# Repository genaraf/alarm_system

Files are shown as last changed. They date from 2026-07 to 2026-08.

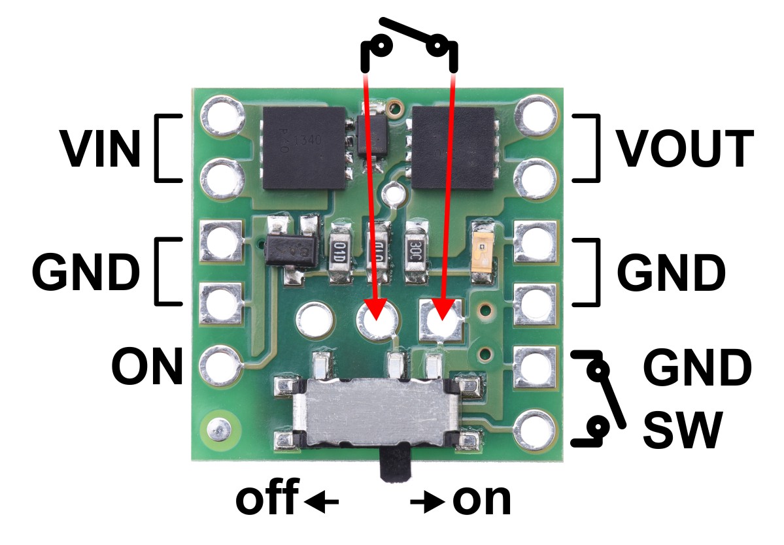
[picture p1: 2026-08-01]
doc/mosfet switch.jpg

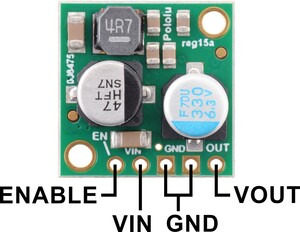
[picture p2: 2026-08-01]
doc/dc-dc.jpg

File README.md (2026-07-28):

# Alarm System on Blynk IoT + ESP32-C3

Проект реализует сирену на `ESP32-C3` с управлением через `Blynk IoT`.

## Hardware

Референсная аппаратная конфигурация для этого проекта:

- Плата: [ESP32-C3 Super Mini](https://www.espboards.dev/esp32/esp32-c3-super-mini/)
- Ключ питания нагрузки: [Pololu Mini MOSFET Slide Switch with Reverse Voltage Protection, SV (item 2811)](https://www.pololu.com/product/2811)
- Понижающий преобразователь питания: [Pololu 5V, 2.5A Step-Down Voltage Regulator D24V25F5 (item 2850)](https://www.pololu.com/product/2850)
- Сирена `12V`: [AliExpress product link](https://aliexpress.com/item/1005007682313103.html)

### Схема подключения

Ниже референсная схема в стиле `KiCad ASCII` для варианта, где входное питание `VIN = 12V`, `Pololu 2850` питает `ESP32` по линии `+5V_SYS`, а `Pololu 2811` коммутирует `12V` на сирену.

```text
Net labels:
  +12V_IN   = входное питание 12 V DC
  +5V_SYS   = выход U2, питание ESP32
  GND       = общая земля
  SIREN_SW  = коммутируемый +12V на сирену

 J1  Screw_Terminal_01x02                    U2  Pololu D24V25F5  (#2850)
 .-----------------------.                  .-----------------------------------.
 | 1  +12V_IN -----------+------------------| VIN                          VOUT |----+---- +5V_SYS
 | 2  GND ---------------+------------------| GND                           EN  |    |    (5 V / 2.5 A)
 '-----------------------'                  '-----------------------------------'

 +5V_SYS ---------------------------------------------------------------> U1:5V
 GND -------------------------------------------------------------------> U1:GND
 GPIO4 -----------------------------------------------------------------> U3:ON
 +12V_IN ---------------------------------------------------------------> U3:VIN
 GND -------------------------------------------------------------------> U3:GND

                                            U1  ESP32-C3 Super Mini
                                           .---------------------------------.
                                           | 5V                              |
                                           | GND                             |
                                           | GPIO4                           |
                                           | GPIO8 -> onboard STATUS LED     |
                                           | GPIO9 -> onboard BOOT button    |
                                           '---------------------------------'

                                            U3  Pololu 2811  (#2811)
                                           .--------------------------------.
                                           | VIN  <---------------- +12V_IN |
                                           | GND  <--------------------- GND |
                                           | ON   <------------------- GPIO4 |
                                           | VOUT ----------------> SIREN_SW |
                                           '--------------------------------'
                                                             |
                                                             |
 J2  Screw_Terminal_01x02                                    |
 .-----------------------.                                   |
 | 1  SIREN+ <-----------+-------------------- SIREN_SW ------+
 | 2  SIREN- <-----------+------------------------ GND -------+
 '-----------------------'
```

Обозначения и номиналы:

- `J1` -> входной клеммник `2 pin`, `12 V DC`
- `U2` -> `Pololu 2850 / D24V25F5`, buck `12 V -> 5 V`, до `2.5 A`
- `U1` -> `ESP32-C3 Super Mini`, питание через вывод `5V`
- `U3` -> `Pololu 2811`, high-side load switch для сирены
- `J2` -> выходной клеммник `2 pin` на сирену `12 V` (см. ссылку выше)

Правила подключения:

- переведите slide switch на `U3` (`Pololu 2811`) в положение `OFF`, если сиреной управляет `GPIO4`
- `GPIO4` подключите к входу `ON` модуля `U3`
- `VIN` модуля `U3` подключите к `+12V_IN`
- `VOUT` модуля `U3` подключите к `SIREN+`
- `SIREN-` подключите к общему `GND`
- `EN` у `U2` оставьте неподключенным

Если плата `ESP32-C3 Super Mini` питается от `USB-C` вместо `U2`, землю `GND` между `ESP32`, `U3` и сиреной все равно нужно объединить.

Текущие GPIO по проекту:

- `GPIO4` -> управление сиреной, силовым ключом или внешним драйвером нагрузки
- `GPIO8` -> статусный LED
- `GPIO9` -> кнопка `BOOT` для `reconfigure`

Важно для `ESP32-C3 Super Mini`:

- `GPIO8` и `GPIO9` относятся к strapping pins
- `GPIO8` должен оставаться в высоком уровне во время reset, иначе загрузка/прошивка может работать нестабильно
- `GPIO9` управляет boot mode: `LOW` при reset переводит чип в download mode
- если используете внешний LED на `GPIO8`, не делайте схему, которая тянет линию вниз при старте

По данным источников:

- `ESP32-C3 Super Mini` — компактная плата на `ESP32-C3` с `4 MB` flash, native USB и выведенными `GPIO8`/`GPIO9`
- модуль `Pololu 2811` — компактный high-side MOSFET power switch с защитой от переполюсовки; его можно использовать как электронный выключатель питания нагрузки
- модуль `Pololu 2850` — понижающий DC-DC регулятор `5 V / 2.5 A` с входным диапазоном `6 V – 38 V`; в этой схеме он используется как источник `5 V` для `ESP32` и низковольтной части устройства
- сирена подключается к `J2` и коммутируется модулем `Pololu 2811` по линии `12 V`
- в этой референсной схеме предполагается `VIN = 12V`

Что умеет прошивка:
- включает сирену на заданное количество секунд;
- выключает сирену по `0` или по таймеру;
- публикует оставшееся время в секундах;
- публикует текущий `Wi-Fi RSSI` в `dBm`;
- поддерживает presets для простого UI и прямое API-управление.

## Datastream'ы

Обязательные:
- `V0` (`Integer`): API управления. Передайте число секунд для старта, `0` для остановки.
- `V1` (`Integer`): отображение оставшегося времени в секундах.

UI для человека:
- `V2` (`Integer` или `Enumerable`): preset menu `0..5`
- `V3` (`Integer`): кнопка `Start`
- `V4` (`Integer`): кнопка `Stop`
- `V5` (`Integer`, опционально): состояние сирены, `1` или `0`
- `V6` (`Integer`, опционально): текущий `Wi-Fi RSSI` в `dBm`

Итоговая конфигурация template:

| Name | Pin | Type | Widget | Назначение |
|---|---|---|---|---|
| `V0` | `V0` | `Integer` | нет | внешний API: `N` секунд / `0` стоп |
| `V1` | `V1` | `Integer` | `Formatted Text`, `Value Display` или `Labeled Value` | оставшееся время в секундах |
| `V2` | `V2` | `Integer` или `Enumerable` | `Menu` / `Dropdown` | preset `0..5` |
| `V3` | `V3` | `Integer` | `Button` `Push` | `Start` |
| `V4` | `V4` | `Integer` | `Button` `Push` | `Stop` |
| `V5` | `V5` | `Integer` | `LED` или `State` | состояние сирены `1/0` |
| `V6` | `V6` | `Integer` | `Value Display` / `Labeled Value` | `Wi-Fi RSSI` в `dBm`, например `-67` |

Важно:
- в `Blynk` поле `Name` должно совпадать с `V`-именем, то есть `V0`, `V1`, `V2`, `V3`, `V4`, `V5`, `V6`
- для этой прошивки одного совпадения `Pin` недостаточно, потому что `Blynk MQTT API` публикует значения по имени datastream

## Рекомендованный UI в Blynk

Сделайте на дашборде:
- `Value Display` или `Labeled Value` для `V1`
- `Menu` или `Dropdown` для `V2`
- кнопку `Start` на `V3` в режиме `Push`
- кнопку `Stop` на `V4` в режиме `Push`
- для обеих кнопок включите подтверждение (`confirmation`)
- при необходимости добавьте `LED` или `State` на `V5`
- для `V6` добавьте `Value Display` и подпись вроде `Wi-Fi RSSI`

Preset items для `V2` должны идти строго в таком порядке:
- `0` -> `5s`
- `1` -> `10s`
- `2` -> `30s`
- `3` -> `60s`
- `4` -> `5m`
- `5` -> `30m`

Логика:
- пользователь выбирает preset в `V2`
- нажимает `Start`
- контроллер запускает сирену на соответствующее время
- `V1` показывает оставшееся число секунд
- `Stop` немедленно выключает сирену

Если нужно управление из внешней автоматизации, используйте только `V0`:
- `V0 = N` запускает сирену на `N` секунд
- `V0 = 0` выключает сирену

## Настройка прошивки

Перед сборкой задайте свой Blynk template:

```bash
idf.py menuconfig
```

Нужно заполнить:
- `Component config -> Blynk.Edgent -> Template ID`
- `Component config -> Blynk.Edgent -> Template Name`

При необходимости настройте:
- `Alarm system -> Siren GPIO`
- `Alarm system -> Siren active GPIO level`
- `Alarm system -> Reconfigure button GPIO`
- `Alarm system -> Status LED GPIO`
- `Alarm system -> Blynk Wi-Fi RSSI datastream`

Плейсхолдеры в `sdkconfig`:
- `TMPLXXXXXX`
- `Alarm System`

их нужно заменить на реальные значения вашего Blynk Template.

## Сборка

```bash
./idf.sh build
./idf.sh -p /dev/ttyACM0 flash monitor
```

Если увидите ошибку вида:

```text
Tool doesn't match supported version from list ['esp-14.2.0_20260121']
... esp-14.2.0_20251107 ...
```

то у вас локальный `ESP-IDF` уже ожидает новый toolchain, а в окружении остался старый.
В этом проекте `./idf.sh` заранее экспортирует `IDF_MAINTAINER=1`, чтобы такая проверка стала предупреждением, а не фатальной ошибкой.

Если хотите исправить окружение правильно, а не обходить проверку, переустановите инструменты для текущего `ESP-IDF`:

```bash
/home/gena/esp/esp-idf/install.sh esp32c3
```

После этого очистите каталог сборки и пересоберите проект:

```bash
rm -rf build
./idf.sh build
```

## Замечание по памяти flash

В проекте включена разметка под `4MB` flash и OTA-разделы Blynk.
Если у вашей платы другой объём flash, скорректируйте [sdkconfig](/home/gena/work/alarm_system/sdkconfig:1) и [partitions.csv](/home/gena/work/alarm_system/partitions.csv:1).

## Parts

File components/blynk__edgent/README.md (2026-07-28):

# Blynk.Edgent for ESP-IDF

**Blynk.Edgent** is a packaged solution that allows **ESP-IDF** developers to easily connect their devices to the Blynk IoT platform
and take advantage of all its advanced features without the need for extensive coding. 



## Features

- **Blynk.Inject**: connect your devices easily using [**Blynk IoT App**][blynk-apps] (iOS and Android)
  - `BLE`-assisted device provisioning for the best end-user experience
  - `WiFiAP`-based provisioning for devices without BLE support - *(soon)*
- **Network Manager**: Advanced network connection management and troubleshooting
  - `WiFi`: Maintains connection to the most reliable WiFi network (up to 16 configured networks)
  - `Ethernet`: Supports `Static IP` or `DHCP` network configuration
  <!--
  - `Cellular`: Provides connectivity through `2G GSM`, `EDGE`, `3G`, `4G LTE`, `Cat M1`, or `5G` networks using `PPP`
  -->
- Secure **Blynk.Cloud** MQTT connection that provides simple API for:
  - Data transfer with `DataStreams`, reporting `Events`, and accessing `Metadata`
- **Blynk.Air** - automatic, managed Over The Air firmware updates using Web Dashboard
  - Direct firmware upgrade using iOS/Android App before device activation - *(soon)*

Supported targets:
```
✅ ESP32, ESP32-S3, ESP32-C2, ESP32-C3, ESP32-C5, ESP32-C6
⏳ ESP32-S2 - coming soon
❌ ESP32-P4, ESP32-H4
```

> [!IMPORTANT]
> Blynk.Edgent component is provided for specific ESP-IDF versions.  
> See the [Release Notes](https://github.com/Blynk-Technologies/Edgent-ESP-IDF/releases) for compatibility details.

## Getting Started

- Sign up/Log in to your [Blynk Account](https://blynk.cloud)
- Install **Blynk IoT App** for [iOS][blynk-ios] or [Android][blynk-android]
- Create a new Product Template. This will provide you with `Template ID` and `Template Name`.

## 1. Build firmware

```sh
idf.py create-project-from-example "blynk/edgent:basic"
cd basic

# Configure the target chip
idf.py set-target esp32

# Configure Blynk.Edgent component
idf.py menuconfig
```

In `menuconfig`, navigate to:

```txt
(Top) → Component config → Blynk.Edgent
```

- Set `Template ID`
- Set `Template Name`
- Save configuration and exit
- Build and flash firmware

## 2. Connect your device to Blynk.Cloud

1. Open **Blynk IoT App** on your smartphone
2. Click **Add device** -> **Find devices nearby**
3. Select your device and follow the wizard instructions

The device should appear `online` once the above steps complete successfully.

<details><summary><b>Expected device log</b></summary>

See the device log via `idf.py monitor`:

```log
I (771) edgent.c: Blynk.Edgent initialized (device: Blynk Demo-N1A9)
I (771) edgent.c: State: IDLE => CONNECTING_NET
I (771) example: State change event received
I (851) nm_wifi.c: Connecting to SSID:wifi BSSID 2c:c8:1b:xx:xx:xx CH:11
I (851) example: Awaiting Cloud connection...
I (1931) edgent.c: State: CONNECTING_NET => CONNECTING_CLOUD
I (1931) example: State change event received
I (2981) edgent.c: State: CONNECTING_CLOUD => RUNNING
I (2981) example: State change event received
I (2981) example: Initial connection established
I (2991) example: [main] Cloud connected event received! Continuing...
```

</details>

<!--
> [!NOTE]
> If you have already created your device in Blynk,
> you can [connect it manually using REPL](_extra/Cookbook.md#manual-device-connection)
-->

The example application also handles the on-board button:

- **Double click** – start provisioning without resetting the previous configuration, allowing reconfiguration.  
- **Long press** – perform a full configuration reset and start provisioning.

## Adding to existing project

```sh
idf.py add-dependency "blynk/edgent"
```

If your project uses [`MINIMAL_BUILD`](https://docs.espressif.com/projects/esp-idf/en/stable/esp32/api-guides/build-system.html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), consider disabling it, or add build dependencies explicitly:
```
esp_event esp_netif esp_wifi esp_https_ota
esp_partition efuse nvs_flash mqtt json bt esp_eth
```

## OTA configuration

Minimum flash size requirement for OTA updates is `4MB`.

You should select a dual-bank partition table, for example:
```txt
(Top) → Partition Table → Partition Table → Two large size OTA partitions
```

## Ethernet configuration

To enable Ethernet:

1. Go to: **Top → Component config → Blynk.Edgent**  
   and enable the **"Use Ethernet"** option.

2. Then go to: **Top → Example Ethernet Configuration**  
   and configure the adapter according to type, options, and pins.

> Example: `sdkconfig.T-Internet-POE` file contains a sample configuration for the [LilyGO T-Internet-POE](https://lilygo.cc/products/t-internet-poe) board.

# Further reading

<!--
- [Cookbook](_extra/Cookbook.md)
-->

- [Blynk.Edgent](https://docs.blynk.io/en/blynk.edgent/overview)
- [Blynk IoT Apps][blynk-apps]
- [Deploying Products With Dynamic AuthTokens](https://docs.blynk.io/en/commercial-use/deploying-products-with-dynamic-authtokens)
- [Blynk MQTT API](https://docs.blynk.io/en/blynk.cloud-mqtt-api/device-mqtt-api)
- [Blynk Network Co-Processor (NCP)](https://docs.blynk.io/en/blynk.ncp/overview)

[blynk-apps]: https://docs.blynk.io/en/downloads/blynk-apps-for-ios-and-android
[blynk-android]: https://play.google.com/store/apps/details?id=cloud.blynk
[blynk-ios]: https://apps.apple.com/us/app/blynk-iot/id1559317868
[blynk_sales]: https://blynk.io/en/contact-us-business

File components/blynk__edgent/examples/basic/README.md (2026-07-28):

# Blynk Edgent ESP-IDF Example

This example demonstrates how to integrate **Blynk Edgent** with **ESP-IDF**, quickly provision and connect device to **Blynk Cloud**.

The application shows how to:

- Initialize **Blynk Edgent**
- Handle device **state change events**
- Receive **downlink messages**
- Send **datastream updates**
- Use a **boot button** for configuration and reset

---

# Supported Targets

| Target | Boot Button GPIO |
|---|---|
| ESP32 | GPIO0 |
| ESP32-S3 | GPIO0 |
| ESP32-C2 | GPIO9 |
| ESP32-C3 | GPIO9 |
| ESP32-C5 | GPIO9 |
| ESP32-C6 | GPIO9 |

---

# Button Actions

The boot button is used to control device provisioning.

| Action | Result |
|---|---|
| Double click | Start configuration mode |
| Long press (5 seconds) | Reset device configuration |

---

# Requirements

- **ESP-IDF ≥ 5.1**
- Blynk Cloud account
- Device Template created in Blynk Console

ESP-IDF installation guide:

https://docs.espressif.com/projects/esp-idf

---

## Configure Blynk Template

Set your Blynk template information using **menuconfig** under **Component config → Blynk.Edgent**.

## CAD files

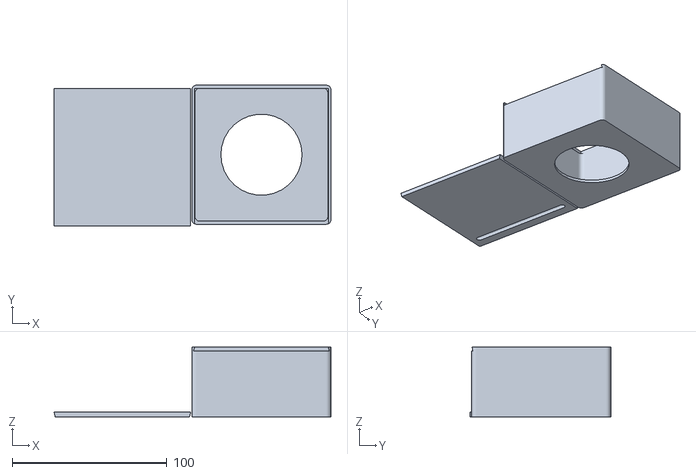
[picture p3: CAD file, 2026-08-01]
doc/alarm_box.stl
179.2 x 91.0 x 45.0

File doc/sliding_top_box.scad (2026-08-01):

/* [Outside Dimensions] */
// width
boxX = 90; 
// depth
boxY = 90; 
// height
boxZ = 45;
// radius of curved corners
cornerRad = 3; 
// thickness of box walls
wallThick = 2; 

/* [Compartments] */
// number of columns
xCompartments = 3;
// number of rows - THIS FEATURE IS DELIBERATELY DISABLED. Please see the summar & lessons below!
yCompartments = 2; 
// thickness of divider walls
dividerThick = 0; 

/* [Lid] */
// amount of play in the lid in mm - the lid can't be the exact same size as the opening
lidSnugness = 0.5;

/* 
  This section is "hidden" from the customizer and is used for calculating
  variables based on those that the user inputs above
*/

/* [Hidden] */
// define the amount that needs to be subtracted to account for wall thicknesses
wallSub = 2 * wallThick;

// to avoid "z fighting" where surfaces line up exactly, add a bit of fudge
fudge = .001; 




/*
  OpenSCAD Parametric Box Lesson

  Created by Aaron Ciuffo (aaron.ciuffo/txoof) - reach me at gmail or thingiverse

  December 16 2015

  Released under the Creative Commons Share Alike License
  http://creativecommons.org/licenses/by-sa/3.0/

  Thanks to:
  agalavis: http://www.thingiverse.com/agalavis (Nail slot issue!)
  0707070: http://www.thingiverse.com/0707070 (issues with lid size)

  Style Notes:
    * Indentation is used to show nested calls:

      union() {
        // one indention to show that all calls are part of the union call
        cube([x, y, z], center = true)
        sphere(r = radius, center = true)
      }

    * cammelCaps are used to name variables to make them readable:
      - this allows more descriptive and readable variable names
      
      lidLength = 5 versus lidlength or lidl
      boxCutOut = 4 versus boxcutout boxc
    
    * Long commands are split over multiple lines using indenation
      - this makes code more readable in all editors and makes relationships
        more clear

      translate([0, lY/2-wall/2, -wall+catch/2]) 
        cube([lX*.8, catch*1.5, catch*1.3], center=true);

*/



/* 
  Add a ready made library for making rounded boxes
  Learn more about the MCAD libraries here: http://reprap.org/wiki/MCAD
*/
include <MCAD/boxes.scad>


/*
  Create the lid trapezoidal lid
  This sub creates both a lid and is used for cutting out the lid shape in the basic box
*/

snugness = 0.5;
module lid(cutter = false) {
  /*
    Lid profile

       boxX - 2* wall thickness + 2*(wall thickness/tan(trap angle))
    p0 ---------------- p1
       \) trap angle  /
        \            /
    P3   ------------   p2
         boxX - 2* wall thickness
         
  */
    

  // define how snug the fit should be on the lid
  // when this sub is used to "cut" enlarge the dimensions to make the opening larger
  snugness = cutter==false ? 1 : lidSnugness;

  // define the lid width (X)
  lidX = (boxX - wallSub) + snugness;

  // define the length of the lid (Y) 
  lidY = boxY - wallThick + snugness;

  // define the thickness of the lid
  lidZ = wallThick + snugness;

  // define slot dimensions
  slotX = lidX*.9;
  slotY = lidY*.05;


  // define the angle in the trapezoid; this needs to be less than 45 for most printers
  trapAngle = 70;
  lidAdd = wallThick/tan(trapAngle);
  // define points for the trapezoidal lid
  p0 = [0, 0];
  p1 = [lidX, 0];
  p2 = [lidX + lidAdd, lidZ];
  p3 = [0 + -lidAdd , lidZ];
  
  //center the lid

  translate([-lidX/2, -lidZ/2, 0])
    // rotate the lid -90 degrees 
    rotate([-90])
    difference() {
      // draw a polygon using the points above and then extrude
      // linear extrude only works in the Z axis so everything has to be rotated after
      linear_extrude(height = lidY, center = true) 
        polygon([p0, p1, p2, p3], paths = [[0, 1, 2, 3]]); 


      // add a fingernail slot for making opening the lid easier
      // the variable names are a bit wonky because the lid is drawn rotated -90 degrees
      if ( cutter == false) {
        translate([lidX/2, 0, lidY/2-slotY*2])
          roundedBox([slotX, lidZ, slotY], radius = slotY/2, $fn=36);
      }
    }
}

/*
  create the dividers for the columns in the box
*/
module xDividers(innerBoxDim) {
  
  // copy from here

  echo ("This is the xDividers module");
  echo ("innerBoxDim=", innerBoxDim);
  // the number of dividers is always one less than the number of compartments
  cols = xCompartments - 1;

  // calculate the spacing of the dividers based on the dimensions of the inner box

  // element 0 of the innerBoxDim variable contains the X dimension  
  increment = innerBoxDim[0]/xCompartments;

  // if the number of compartments is bigger than 1, do this:
  if ( xCompartments > 1) {
    // this loops several times to make each divider from 1 to the number of columns
    for ( i = [1 : cols]) {
      // move each divider into place
        translate([-innerBoxDim[0]/2+i*increment, 0, 0])
          // draw a cube - remember to remove a bit for the snuggness factor on the lid
          cube([dividerThick, innerBoxDim[1], innerBoxDim[2]-2*snugness], center =true);
      
    } // this bracket is the end of the "for" loop
  } // this bracket is the end of the IF statement
  

  // copy to here

} // this should be the LAST curly bracket for xDividers


/*
  create the dividers for the rows
  You should be able to copy most of the xDiviers module into this module
  and make only minor changes. 
  
  Think about the following things:
  * box/cube modules accept variables as arrays [X, Y, Z] 
  * the first element of an array is called 0, the second 1, etc.
  * use '#' to help debug: 
    https://en.wikibooks.org/wiki/OpenSCAD_User_Manual/The_OpenSCAD_Language#Chapter_8_--_Debugging_aids
*/
module yDividers(innerBoxDim) {
// paste below this point.  Be careful that you pay attention to the curly brackets




} // this should be the LAST curly bracket for yDividers. 


/*
  create the basic box
*/
module basicBox(outerBox, innerBox) {
  // Set the curve refinement
  $fn = 36;


  // Create the box then subtract the inner volume and make a cut for the sliding lid
  difference() {
    // call the MCAD rounded box command imported from MCAD/boxes.scad
    // size = dimensions; radius = corner curve radius; sidesonly = round only some sides

    // First draw the outer box
    roundedBox(size = outerBox, radius = cornerRad, sidesonly = 1);
    // Then cut out the inner box
    roundedBox(size = innerBox, radius = cornerRad, sidesonly = 1);
    // Then cut out the lid
    translate([0, 0, (boxZ/2)+fudge])
      lid(cutter = true); 
  }
}

/*
  This module will call all of the other modules and assemble the final box
*/
module dividedBox() {
  echo ("This is the dividedBox module");
  // Define the volume that will be the outer box
  outerBox = [boxX, boxY, boxZ];

  // Define the volume that will be subtracted from the box
  // a "fudge factor" is added to avoid Z fighting when faces align perfectly
  innerBox = [boxX-wallSub, boxY-wallSub, boxZ-wallSub+fudge*2];

  // call the basic box module to add the box
  difference() {
    basicBox(outerBox, innerBox);
    translate([0, 0, 0]) cylinder(d=52.5, h = 100, center=true);
  }
  // explain what's going on
  echo ("innerBox=", innerBox);

  // draw the dividers in the X dimension
  xDividers(innerBox);

  // draw the dividers in the Y dimension
  #yDividers(); // the # will highlight this in red when it is drawn


  // move the lid to the left of the box and also move it down  so it sits at the
  // same level as the bottom of the box
  //translate([-boxX, 0, -boxZ/2+wallThick/2])
  translate([-boxX, 0, -boxZ/2])
    rotate([0, 180, 0])
    lid();
}

// call the dividedBox module
dividedBox();    

//lid();

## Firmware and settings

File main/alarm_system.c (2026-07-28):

#include <ctype.h>
#include <errno.h>
#include <inttypes.h>
#include <stdbool.h>
#include <stdint.h>
#include <stdio.h>
#include <stdlib.h>
#include <string.h>

#include "blynk_edgent.h"
#include "driver/gpio.h"
#include "esp_err.h"
#include "esp_event.h"
#include "esp_log.h"
#include "esp_system.h"
#include "esp_timer.h"
#include "esp_wifi.h"
#include "freertos/FreeRTOS.h"
#include "freertos/semphr.h"
#include "freertos/task.h"
#include "nvs_flash.h"
#include "sdkconfig.h"

#ifndef CONFIG_ALARM_SIREN_GPIO
#define CONFIG_ALARM_SIREN_GPIO 4
#endif

#ifndef CONFIG_ALARM_SIREN_ACTIVE_LEVEL
#define CONFIG_ALARM_SIREN_ACTIVE_LEVEL 1
#endif

#ifndef CONFIG_ALARM_SIREN_CONTROL_DS
#define CONFIG_ALARM_SIREN_CONTROL_DS "V0"
#endif

#ifndef CONFIG_ALARM_SIREN_TIME_DS
#define CONFIG_ALARM_SIREN_TIME_DS "V1"
#endif

#ifndef CONFIG_ALARM_SIREN_PRESET_DS
#define CONFIG_ALARM_SIREN_PRESET_DS "V2"
#endif

#ifndef CONFIG_ALARM_SIREN_START_DS
#define CONFIG_ALARM_SIREN_START_DS "V3"
#endif

#ifndef CONFIG_ALARM_SIREN_STOP_DS
#define CONFIG_ALARM_SIREN_STOP_DS "V4"
#endif

#ifndef CONFIG_ALARM_SIREN_STATE_DS
#define CONFIG_ALARM_SIREN_STATE_DS "V5"
#endif

#ifndef CONFIG_ALARM_RECONFIG_BUTTON_GPIO
#define CONFIG_ALARM_RECONFIG_BUTTON_GPIO 9
#endif

#ifndef CONFIG_ALARM_RECONFIG_BUTTON_ACTIVE_LEVEL
#define CONFIG_ALARM_RECONFIG_BUTTON_ACTIVE_LEVEL 0
#endif

#ifndef CONFIG_ALARM_STATUS_LED_GPIO
#define CONFIG_ALARM_STATUS_LED_GPIO 8
#endif

#ifndef CONFIG_ALARM_STATUS_LED_ACTIVE_LEVEL
#define CONFIG_ALARM_STATUS_LED_ACTIVE_LEVEL 1
#endif

#ifndef CONFIG_ALARM_WIFI_RSSI_DS
#define CONFIG_ALARM_WIFI_RSSI_DS "V6"
#endif

#ifndef CONFIG_ALARM_WIFI_RSSI_PUBLISH_INTERVAL_SECONDS
#define CONFIG_ALARM_WIFI_RSSI_PUBLISH_INTERVAL_SECONDS 15
#endif

#define MAX_HOURS_VALUE      99U
#define MAX_MINSEC_VALUE     59U
#define MAX_SIREN_SECONDS    ((MAX_HOURS_VALUE * 3600U) + (MAX_MINSEC_VALUE * 60U) + MAX_MINSEC_VALUE)
#define TIMER_POLL_INTERVAL_MS 1000U
#define DEFAULT_PRESET_INDEX 0U
#define BUTTON_POLL_INTERVAL_MS 20U
#define BUTTON_DEBOUNCE_MS 30U
#define BUTTON_DOUBLE_CLICK_TIMEOUT_MS 400U
#define BUTTON_LONG_PRESS_MS 5000U
#define STATUS_LED_FAST_BLINK_MS 125U
#define STATUS_LED_SLOW_BLINK_MS 500U
#define STATUS_LED_ERROR_BLINK_MS 75U

static const uint32_t SIREN_PRESET_SECONDS[] = {
    5U,
    10U,
    30U,
    60U,
    300U,
    1800U,
};

typedef struct {
    uint32_t selected_preset_index;
    uint32_t last_published_remaining_seconds;
    int64_t stop_time_us;
    bool siren_enabled;
} siren_state_t;

typedef enum {
    STATUS_LED_PATTERN_OFF = 0,
    STATUS_LED_PATTERN_ON,
    STATUS_LED_PATTERN_BLINK_FAST,
    STATUS_LED_PATTERN_BLINK_SLOW,
    STATUS_LED_PATTERN_BLINK_ERROR,
} status_led_pattern_t;

static const char *TAG = "alarm_system";

static siren_state_t s_siren_state;
static SemaphoreHandle_t s_siren_mutex;
static TaskHandle_t s_siren_task_handle;
static esp_timer_handle_t s_siren_timer;
static volatile status_led_pattern_t s_status_led_pattern = STATUS_LED_PATTERN_BLINK_FAST;
static bool s_edgent_connected;
static bool s_wifi_rssi_published;
static int8_t s_last_wifi_rssi;
static TickType_t s_last_wifi_rssi_publish_tick;

static size_t siren_preset_count(void)
{
    return sizeof(SIREN_PRESET_SECONDS) / sizeof(SIREN_PRESET_SECONDS[0]);
}

static bool siren_preset_index_is_valid(uint32_t index)
{
    return index < siren_preset_count();
}

static uint32_t siren_preset_seconds_from_index(uint32_t index)
{
    if (!siren_preset_index_is_valid(index)) {
        index = DEFAULT_PRESET_INDEX;
    }

    return SIREN_PRESET_SECONDS[index];
}

static bool siren_find_preset_index(uint32_t seconds, uint32_t *index)
{
    size_t i;

    for (i = 0; i < siren_preset_count(); ++i) {
        if (SIREN_PRESET_SECONDS[i] == seconds) {
            if (index != NULL) {
                *index = (uint32_t)i;
            }
            return true;
        }
    }

    return false;
}

static uint32_t clamp_u32(uint32_t value, uint32_t max_value)
{
    return value > max_value ? max_value : value;
}

static bool topic_matches_datastream(const char *topic, int topic_len, const char *datastream)
{
    const size_t datastream_len = strlen(datastream);

    if (topic_len < (int)datastream_len) {
        return false;
    }

    return memcmp(topic + topic_len - datastream_len, datastream, datastream_len) == 0;
}

static bool parse_non_negative_u32(const char *data, int data_len, uint32_t *value)
{
    char buffer[24];
    char *start = buffer;
    char *end = NULL;
    unsigned long parsed;

    if (data_len <= 0 || data_len >= (int)sizeof(buffer) || value == NULL) {
        return false;
    }

    memcpy(buffer, data, data_len);
    buffer[data_len] = '\0';

    while (*start != '\0' && isspace((unsigned char)*start)) {
        start++;
    }

    if (*start == '\0') {
        return false;
    }

    end = start + strlen(start) - 1;
    while (end >= start && isspace((unsigned char)*end)) {
        *end = '\0';
        end--;
    }

    errno = 0;
    parsed = strtoul(start, &end, 10);
    if (errno != 0 || end == start || *end != '\0' || parsed > UINT32_MAX) {
        return false;
    }

    *value = (uint32_t)parsed;
    return true;
}

static void siren_set_gpio(bool enabled)
{
    const int on_level = CONFIG_ALARM_SIREN_ACTIVE_LEVEL ? 1 : 0;
    const int off_level = on_level ? 0 : 1;

    gpio_set_level(CONFIG_ALARM_SIREN_GPIO, enabled ? on_level : off_level);
}

static void status_led_set_gpio(bool enabled)
{
    const int on_level = CONFIG_ALARM_STATUS_LED_ACTIVE_LEVEL ? 1 : 0;
    const int off_level = on_level ? 0 : 1;

    gpio_set_level(CONFIG_ALARM_STATUS_LED_GPIO, enabled ? on_level : off_level);
}

static const char *edgent_state_to_str(edgent_state_t state)
{
    switch (state) {
    case EDGENT_STATE_UNKNOWN:
        return "UNKNOWN";
    case EDGENT_STATE_IDLE:
        return "IDLE";
    case EDGENT_STATE_CONNECTING_NET:
        return "CONNECTING_NET";
    case EDGENT_STATE_CONNECTING_CLOUD:
        return "CONNECTING_CLOUD";
    case EDGENT_STATE_CONNECTED:
        return "CONNECTED";
    case EDGENT_STATE_WAIT_CONFIG:
        return "WAIT_CONFIG";
    case EDGENT_STATE_OTA_UPGRADE:
        return "OTA_UPGRADE";
    case EDGENT_STATE_ERROR:
        return "ERROR";
    default:
        return "INVALID";
    }
}

static status_led_pattern_t status_led_pattern_from_state(edgent_state_t state)
{
    switch (state) {
    case EDGENT_STATE_CONNECTED:
        return STATUS_LED_PATTERN_ON;
    case EDGENT_STATE_WAIT_CONFIG:
        return STATUS_LED_PATTERN_BLINK_SLOW;
    case EDGENT_STATE_ERROR:
        return STATUS_LED_PATTERN_BLINK_ERROR;
    case EDGENT_STATE_IDLE:
    case EDGENT_STATE_CONNECTING_NET:
    case EDGENT_STATE_CONNECTING_CLOUD:
    case EDGENT_STATE_OTA_UPGRADE:
    case EDGENT_STATE_UNKNOWN:
    default:
        return STATUS_LED_PATTERN_BLINK_FAST;
    }
}

static void status_led_set_pattern(status_led_pattern_t pattern)
{
    s_status_led_pattern = pattern;
}

static void publish_remaining_time(uint32_t remaining_seconds)
{
    const edgent_err rc = edgent_publish_ds_int(CONFIG_ALARM_SIREN_TIME_DS, remaining_seconds);

    if (rc != EDGENT_OK) {
        ESP_LOGW(TAG, "Failed to publish remaining time: %" PRIu32 " s, rc=%d", remaining_seconds, rc);
        return;
    }

    ESP_LOGI(TAG, "Published remaining time: %" PRIu32 " s", remaining_seconds);
}

static void publish_selected_preset(uint32_t preset_index)
{
    edgent_publish_ds_int(CONFIG_ALARM_SIREN_PRESET_DS, preset_index);
}

static void publish_running_state(bool enabled)
{
    const int state_value = enabled ? 1 : 0;
    const edgent_err rc = edgent_publish_ds_int(CONFIG_ALARM_SIREN_STATE_DS, state_value);

    if (rc != EDGENT_OK) {
        ESP_LOGW(TAG, "Failed to publish siren state: %d, rc=%d", state_value, rc);
        return;
    }

    ESP_LOGI(TAG, "Published siren state: %d", state_value);
}

static void publish_wifi_rssi(int8_t rssi)
{
    const edgent_err rc = edgent_publish_ds_int(CONFIG_ALARM_WIFI_RSSI_DS, rssi);

    if (rc != EDGENT_OK) {
        ESP_LOGW(TAG, "Failed to publish Wi-Fi RSSI: %d dBm, rc=%d", rssi, rc);
        return;
    }

    s_last_wifi_rssi = rssi;
    s_last_wifi_rssi_publish_tick = xTaskGetTickCount();
    s_wifi_rssi_published = true;

    ESP_LOGI(TAG, "Published Wi-Fi RSSI: %d dBm", rssi);
}

static void maybe_publish_wifi_rssi(bool force)
{
    wifi_ap_record_t ap_info;
    const TickType_t now = xTaskGetTickCount();
    const TickType_t min_interval_ticks = pdMS_TO_TICKS(CONFIG_ALARM_WIFI_RSSI_PUBLISH_INTERVAL_SECONDS * 1000U);
    esp_err_t err;

    if (!s_edgent_connected) {
        return;
    }

    if (!force && s_wifi_rssi_published &&
        (now - s_last_wifi_rssi_publish_tick) < min_interval_ticks) {
        return;
    }

    err = esp_wifi_sta_get_ap_info(&ap_info);

    if (err == ESP_OK) {
        if (force || !s_wifi_rssi_published || ap_info.rssi != s_last_wifi_rssi) {
            publish_wifi_rssi(ap_info.rssi);
        } else {
            s_last_wifi_rssi_publish_tick = now;
        }
        return;
    }

    if (err != ESP_ERR_WIFI_CONN && err != ESP_ERR_WIFI_NOT_CONNECT) {
        ESP_LOGW(TAG, "Failed to read Wi-Fi RSSI: %s", esp_err_to_name(err));
    }
}

static void reset_button_datastreams(void)
{
    edgent_publish_ds_int(CONFIG_ALARM_SIREN_START_DS, 0);
    edgent_publish_ds_int(CONFIG_ALARM_SIREN_STOP_DS, 0);
}

static void stop_timer_if_running(void)
{
    const esp_err_t err = esp_timer_stop(s_siren_timer);

    if (err != ESP_OK && err != ESP_ERR_INVALID_STATE) {
        ESP_LOGW(TAG, "Failed to stop timer: %s", esp_err_to_name(err));
    }
}

static void siren_stop(void)
{
    stop_timer_if_running();

    xSemaphoreTake(s_siren_mutex, portMAX_DELAY);
    s_siren_state.siren_enabled = false;
    s_siren_state.stop_time_us = 0;
    s_siren_state.last_published_remaining_seconds = 0;
    xSemaphoreGive(s_siren_mutex);

    siren_set_gpio(false);
    publish_remaining_time(0);
    edgent_publish_ds_int(CONFIG_ALARM_SIREN_CONTROL_DS, 0);
    publish_running_state(false);
    reset_button_datastreams();

    ESP_LOGI(TAG, "Siren stopped");
}

static void siren_start(uint32_t seconds)
{
    const uint32_t safe_seconds = clamp_u32(seconds, MAX_SIREN_SECONDS);
    uint32_t matched_preset_index = DEFAULT_PRESET_INDEX;
    const bool preset_matched = siren_find_preset_index(safe_seconds, &matched_preset_index);

    if (safe_seconds == 0) {
        siren_stop();
        return;
    }

    stop_timer_if_running();

    xSemaphoreTake(s_siren_mutex, portMAX_DELAY);
    if (preset_matched) {
        s_siren_state.selected_preset_index = matched_preset_index;
    }
    s_siren_state.last_published_remaining_seconds = safe_seconds;
    s_siren_state.stop_time_us = esp_timer_get_time() + ((int64_t)safe_seconds * 1000000LL);
    s_siren_state.siren_enabled = true;
    xSemaphoreGive(s_siren_mutex);

    siren_set_gpio(true);
    ESP_ERROR_CHECK(esp_timer_start_once(s_siren_timer, (uint64_t)safe_seconds * 1000000ULL));

    if (preset_matched) {
        publish_selected_preset(matched_preset_index);
    }
    publish_remaining_time(safe_seconds);
    edgent_publish_ds_int(CONFIG_ALARM_SIREN_CONTROL_DS, safe_seconds);
    publish_running_state(true);
    reset_button_datastreams();

    ESP_LOGI(TAG, "Siren started for %" PRIu32 " s", safe_seconds);
}

static void siren_timer_callback(void *arg)
{
    (void)arg;

    if (s_siren_task_handle != NULL) {
        xTaskNotifyGive(s_siren_task_handle);
    }
}

static void siren_publish_full_state(void)
{
    bool enabled;
    uint32_t preset_index;
    uint32_t remaining_seconds = 0;

    xSemaphoreTake(s_siren_mutex, portMAX_DELAY);
    enabled = s_siren_state.siren_enabled;
    preset_index = s_siren_state.selected_preset_index;

    if (enabled && s_siren_state.stop_time_us > 0) {
        const int64_t remaining_us = s_siren_state.stop_time_us - esp_timer_get_time();
        remaining_seconds = remaining_us > 0 ? (uint32_t)((remaining_us + 999999LL) / 1000000LL) : 0;
    }
    xSemaphoreGive(s_siren_mutex);

    publish_selected_preset(preset_index);
    publish_remaining_time(remaining_seconds);
    edgent_publish_ds_int(CONFIG_ALARM_SIREN_CONTROL_DS, remaining_seconds);
    publish_running_state(enabled && remaining_seconds > 0);
    reset_button_datastreams();
}

static void handle_preset_selection_update(uint32_t preset_index)
{
    if (!siren_preset_index_is_valid(preset_index)) {
        uint32_t current_preset_index;

        xSemaphoreTake(s_siren_mutex, portMAX_DELAY);
        current_preset_index = s_siren_state.selected_preset_index;
        xSemaphoreGive(s_siren_mutex);

        publish_selected_preset(current_preset_index);
        ESP_LOGW(TAG, "Unsupported preset index: %" PRIu32, preset_index);
        return;
    }

    xSemaphoreTake(s_siren_mutex, portMAX_DELAY);
    s_siren_state.selected_preset_index = preset_index;
    xSemaphoreGive(s_siren_mutex);

    publish_selected_preset(preset_index);
    ESP_LOGI(TAG, "Preset selected: index=%" PRIu32 ", seconds=%" PRIu32,
             preset_index, siren_preset_seconds_from_index(preset_index));
}

static void handle_downlink_datastream(const char *topic, int topic_len, const char *data, int data_len)
{
    uint32_t value;

    if (!parse_non_negative_u32(data, data_len, &value)) {
        ESP_LOGW(TAG, "Invalid downlink payload");
        return;
    }

    if (topic_matches_datastream(topic, topic_len, CONFIG_ALARM_SIREN_CONTROL_DS)) {
        siren_start(value);
        return;
    }

    if (topic_matches_datastream(topic, topic_len, CONFIG_ALARM_SIREN_PRESET_DS)) {
        handle_preset_selection_update(value);
        return;
    }

    if (topic_matches_datastream(topic, topic_len, CONFIG_ALARM_SIREN_START_DS)) {
        if (value != 0) {
            uint32_t preset_index;

            xSemaphoreTake(s_siren_mutex, portMAX_DELAY);
            preset_index = s_siren_state.selected_preset_index;
            xSemaphoreGive(s_siren_mutex);

            siren_start(siren_preset_seconds_from_index(preset_index));
        } else {
            reset_button_datastreams();
        }
        return;
    }

    if (topic_matches_datastream(topic, topic_len, CONFIG_ALARM_SIREN_STOP_DS)) {
        if (value != 0) {
            siren_stop();
        } else {
            reset_button_datastreams();
        }
        return;
    }
}

static void on_initial_connection(void)
{
    s_edgent_connected = true;
    siren_publish_full_state();
    maybe_publish_wifi_rssi(true);
}

static void on_edgent_state_changed(void *handler_arg, esp_event_base_t base, int32_t id, void *event_data)
{
    const edgent_state_evt_t *state_event = (const edgent_state_evt_t *)event_data;

    (void)handler_arg;
    (void)base;

    if (id != EDGENT_EVENT_STATE_CHANGED || state_event == NULL) {
        return;
    }

    s_edgent_connected = state_event->curr == EDGENT_STATE_CONNECTED;
    if (!s_edgent_connected) {
        s_wifi_rssi_published = false;
        s_last_wifi_rssi_publish_tick = 0;
    }

    status_led_set_pattern(status_led_pattern_from_state(state_event->curr));
    ESP_LOGI(TAG, "Edgent state: %s -> %s",
             edgent_state_to_str(state_event->prev),
             edgent_state_to_str(state_event->curr));
}

static void on_reboot_request(void)
{
    esp_restart();
}

static void status_led_task(void *arg)
{
    status_led_pattern_t active_pattern = STATUS_LED_PATTERN_OFF;
    bool led_on = false;

    (void)arg;

    while (true) {
        const status_led_pattern_t next_pattern = s_status_led_pattern;

        if (next_pattern != active_pattern) {
            active_pattern = next_pattern;
            led_on = false;
        }

        switch (active_pattern) {
        case STATUS_LED_PATTERN_OFF:
            status_led_set_gpio(false);
            vTaskDelay(pdMS_TO_TICKS(100));
            break;
        case STATUS_LED_PATTERN_ON:
            status_led_set_gpio(true);
            vTaskDelay(pdMS_TO_TICKS(100));
            break;
        case STATUS_LED_PATTERN_BLINK_FAST:
            led_on = !led_on;
            status_led_set_gpio(led_on);
            vTaskDelay(pdMS_TO_TICKS(STATUS_LED_FAST_BLINK_MS));
            break;
        case STATUS_LED_PATTERN_BLINK_SLOW:
            led_on = !led_on;
            status_led_set_gpio(led_on);
            vTaskDelay(pdMS_TO_TICKS(STATUS_LED_SLOW_BLINK_MS));
            break;
        case STATUS_LED_PATTERN_BLINK_ERROR:
            led_on = !led_on;
            status_led_set_gpio(led_on);
            vTaskDelay(pdMS_TO_TICKS(STATUS_LED_ERROR_BLINK_MS));
            break;
        default:
            status_led_set_gpio(false);
            vTaskDelay(pdMS_TO_TICKS(100));
            break;
        }
    }
}

static void reconfig_button_task(void *arg)
{
    const int active_level = CONFIG_ALARM_RECONFIG_BUTTON_ACTIVE_LEVEL ? 1 : 0;
    const TickType_t poll_interval = pdMS_TO_TICKS(BUTTON_POLL_INTERVAL_MS);
    const TickType_t debounce_ticks = pdMS_TO_TICKS(BUTTON_DEBOUNCE_MS);
    const TickType_t double_click_ticks = pdMS_TO_TICKS(BUTTON_DOUBLE_CLICK_TIMEOUT_MS);
    const TickType_t long_press_ticks = pdMS_TO_TICKS(BUTTON_LONG_PRESS_MS);
    TickType_t now = xTaskGetTickCount();
    bool raw_pressed = gpio_get_level(CONFIG_ALARM_RECONFIG_BUTTON_GPIO) == active_level;
    bool stable_pressed = raw_pressed;
    TickType_t raw_changed_at = now;
    TickType_t pressed_at = now;
    TickType_t last_release_at = 0;
    uint32_t click_count = 0;
    bool long_press_handled = false;

    (void)arg;

    while (true) {
        const bool sampled_pressed = gpio_get_level(CONFIG_ALARM_RECONFIG_BUTTON_GPIO) == active_level;

        now = xTaskGetTickCount();

        if (sampled_pressed != raw_pressed) {
            raw_pressed = sampled_pressed;
            raw_changed_at = now;
        }

        if (stable_pressed != raw_pressed && (now - raw_changed_at) >= debounce_ticks) {
            stable_pressed = raw_pressed;

            if (stable_pressed) {
                pressed_at = now;
                long_press_handled = false;
            } else if (!long_press_handled) {
                click_count++;
                last_release_at = now;
            }
        }

        if (stable_pressed && !long_press_handled && (now - pressed_at) >= long_press_ticks) {
            long_press_handled = true;
            click_count = 0;
            ESP_LOGI(TAG, "BOOT long-press detected, resetting Blynk.Edgent config");
            edgent_config_reset();
        } else if (!stable_pressed && click_count > 0 && (now - last_release_at) >= double_click_ticks) {
            if (click_count >= 2U) {
                ESP_LOGI(TAG, "BOOT double-click detected, starting Blynk.Edgent reconfigure");
                edgent_config_start();
            }
            click_count = 0;
        }

        vTaskDelay(poll_interval);
    }
}

static void siren_task(void *arg)
{
    (void)arg;

    while (true) {
        bool should_stop = false;
        bool should_publish = false;
        uint32_t remaining_seconds = 0;

        ulTaskNotifyTake(pdTRUE, pdMS_TO_TICKS(TIMER_POLL_INTERVAL_MS));

        xSemaphoreTake(s_siren_mutex, portMAX_DELAY);
        if (s_siren_state.siren_enabled && s_siren_state.stop_time_us > 0) {
            const int64_t remaining_us = s_siren_state.stop_time_us - esp_timer_get_time();

            if (remaining_us <= 0) {
                should_stop = true;
            } else {
                remaining_seconds = (uint32_t)((remaining_us + 999999LL) / 1000000LL);
                if (remaining_seconds != s_siren_state.last_published_remaining_seconds) {
                    s_siren_state.last_published_remaining_seconds = remaining_seconds;
                    should_publish = true;
                }
            }
        }
        xSemaphoreGive(s_siren_mutex);

        if (should_stop) {
            siren_stop();
        } else if (should_publish) {
            publish_remaining_time(remaining_seconds);
        }

        maybe_publish_wifi_rssi(false);
    }
}

static void init_nvs(void)
{
    esp_err_t err = nvs_flash_init();

    if (err == ESP_ERR_NVS_NO_FREE_PAGES || err == ESP_ERR_NVS_NEW_VERSION_FOUND) {
        ESP_ERROR_CHECK(nvs_flash_erase());
        err = nvs_flash_init();
    }

    ESP_ERROR_CHECK(err);
}

static void init_default_event_loop(void)
{
    const esp_err_t err = esp_event_loop_create_default();

    if (err != ESP_OK && err != ESP_ERR_INVALID_STATE) {
        ESP_ERROR_CHECK(err);
    }
}

static void init_edgent_event_handler(void)
{
    ESP_ERROR_CHECK(esp_event_handler_instance_register(
        EDGENT_EVENT_BASE,
        EDGENT_EVENT_STATE_CHANGED,
        on_edgent_state_changed,
        NULL,
        NULL));
}
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
void app_main(void)
{
    const edgent_config_t edgent_config = {
        .downlink_ds_callback = handle_downlink_datastream,
        .initial_connection_callback = on_initial_connection,
        .reboot_request_callback = on_reboot_request,
    };

    init_nvs();
    init_default_event_loop();
    init_edgent_event_handler();
    siren_init();
    status_led_init();
    reconfig_button_init();
    edgent_init(&edgent_config);
    edgent_start();
}

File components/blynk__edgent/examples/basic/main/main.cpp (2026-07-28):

/*
 * Copyright (c) 2025 Blynk Technologies Inc.
 *
 * SPDX-License-Identifier: Apache-2.0
 */

#include <stdint.h>
#include <stdbool.h>
#include <string.h>
#include <esp_log.h>
#include <esp_system.h>
#include <esp_random.h>
#include <nvs_flash.h>
#include <freertos/FreeRTOS.h>
#include <freertos/task.h>
#include <iot_button.h>
#include <button_gpio.h>
#include "blynk_edgent.h"

static const char* TAG = "example";

static EventGroupHandle_t evt_group;
#define EVT_CONNECTED BIT0

#if CONFIG_IDF_TARGET_ESP32 || CONFIG_IDF_TARGET_ESP32S3
#   define BOOT_BUTTON_NUM 0
#elif CONFIG_IDF_TARGET_ESP32C3 || CONFIG_IDF_TARGET_ESP32C6 || CONFIG_IDF_TARGET_ESP32C2 || CONFIG_IDF_TARGET_ESP32C5
#   define BOOT_BUTTON_NUM 9
#endif
#define BUTTON_ACTIVE_LEVEL 0

static void button_event_cb(void* arg, void* data) {
   iot_button_print_event((button_handle_t)arg);
   button_event_t event = iot_button_get_event((button_handle_t)arg);
   if (BUTTON_LONG_PRESS_START == event) {
      edgent_config_reset();
   } else if (BUTTON_DOUBLE_CLICK == event) {
      edgent_config_start();
   }
}

static void button_init(uint32_t button_num) {
   button_config_t btn_cfg = {.long_press_time = 5000, .short_press_time = 200};
   button_gpio_config_t gpio_cfg = {.gpio_num = (int32_t)button_num,
                                    .active_level = BUTTON_ACTIVE_LEVEL,
                                    .enable_power_save = true,
                                    .disable_pull = true};

   button_handle_t btn;
   esp_err_t ret = iot_button_new_gpio_device(&btn_cfg, &gpio_cfg, &btn);
   assert(ret == ESP_OK);

   ret |= iot_button_register_cb(btn, BUTTON_SINGLE_CLICK, NULL, button_event_cb, NULL);
   ret |= iot_button_register_cb(btn, BUTTON_DOUBLE_CLICK, NULL, button_event_cb, NULL);
   ret |= iot_button_register_cb(btn, BUTTON_LONG_PRESS_START, NULL, button_event_cb, NULL);

   ESP_ERROR_CHECK(ret);
}

static void on_downlink_datastream_callback(const char* topic, int topic_len, const char* data, int data_len) {
   ESP_LOGI(TAG, "Datastream received — topic: %s, data: %s", topic, data);
}

static void on_downlink_callback(const char* topic, int topic_len, const char* data, int data_len) {
   ESP_LOGI(TAG, "Downlink received — topic: %s, data: %s", topic, data);
}

static void on_state_change(void) {
   ESP_LOGI(TAG, "State change event received");
}

static void on_initial_connection(void) {
   ESP_LOGI(TAG, "Initial connection established");
   edgent_get_ds_all();
   edgent_get_utc();
   edgent_get_location();
}

static void on_config_change(void) {
   ESP_LOGI(TAG, "Configuration change detected");
}

void on_reboot_request(void) {
   ESP_LOGI(TAG, "Blynk.Edgent initiated reboot");
   esp_restart();
}

// Event handler
static void blynk_edgent_event_handler(void* handler_arg, esp_event_base_t base, int32_t id, void* event_data) {
   if (id == EDGENT_EVENT_STATE_CHANGED && event_data) {
      edgent_state_evt_t* evt = (edgent_state_evt_t*)event_data;
      ESP_LOGD(TAG, "Blynk.Edgent state changed: %d -> %d", evt->prev, evt->curr);
      switch (evt->curr) {
      case EDGENT_STATE_CONNECTED:
         xEventGroupSetBits(evt_group, EVT_CONNECTED);
         break;
      case EDGENT_STATE_ERROR:
         ESP_LOGW(TAG, "Device entered ERROR state, take action!");
         break;
      default:
         break;
      }
   }
}

void other_task(void* arg) {
   EventBits_t bits = xEventGroupWaitBits(evt_group, EVT_CONNECTED, pdFALSE, pdFALSE, portMAX_DELAY);
   if (bits & EVT_CONNECTED) {
      ESP_LOGI(TAG, "[%s] Cloud connected event received! Continuing...", pcTaskGetName(NULL));
   }

   while (true) {
      double rnd = 10.0 + (esp_random() % 2501) / 100.0;
      edgent_publish_ds_float("Set Temperature", rnd, 2);
      edgent_publish_ds_int("Status", rand() % 5);
      vTaskDelay(pdMS_TO_TICKS(10000));
   }
}

extern "C" void app_main(void) {
   ESP_LOGI(TAG, "app_main() entered");

   /* Suppress log pollution */
   esp_log_level_set("phy_init", ESP_LOG_WARN);
   esp_log_level_set("wifi", ESP_LOG_ERROR);
   esp_log_level_set("wifi_init", ESP_LOG_WARN);
   esp_log_level_set("pp", ESP_LOG_WARN);
   esp_log_level_set("net80211", ESP_LOG_WARN);
   esp_log_level_set("esp_netif_handlers", ESP_LOG_WARN);
   esp_log_level_set("NimBLE", ESP_LOG_WARN);
   esp_log_level_set("mqtt_client", ESP_LOG_WARN);
   esp_log_level_set("esp_image", ESP_LOG_WARN);
   esp_log_level_set("esp_https_ota", ESP_LOG_WARN);

   /* Initialize NVS — it is used to store PHY calibration data */
   esp_err_t ret = nvs_flash_init();
   if (ret == ESP_ERR_NVS_NO_FREE_PAGES || ret == ESP_ERR_NVS_NEW_VERSION_FOUND) {
      ESP_ERROR_CHECK(nvs_flash_erase());
      ret = nvs_flash_init();
   }
   ESP_ERROR_CHECK(ret);

   ESP_ERROR_CHECK(esp_event_loop_create_default());
   ESP_ERROR_CHECK(esp_event_handler_instance_register(
      EDGENT_EVENT_BASE, EDGENT_EVENT_STATE_CHANGED, blynk_edgent_event_handler, NULL, NULL));

   // Create the event group
   evt_group = xEventGroupCreate();
   assert(evt_group);

   // initialize button
   button_init(BOOT_BUTTON_NUM);

   // initialize Edgent
   edgent_config_t config = {};
   config.downlink_ds_callback = on_downlink_datastream_callback;
   config.downlink_callback = on_downlink_callback;
   config.state_change_callback = on_state_change;
   config.config_change_callback = on_config_change;
   config.initial_connection_callback = on_initial_connection;
   config.reboot_request_callback = on_reboot_request;
   edgent_init(&config);

   // start Edgent
   edgent_start();

   // create parallel task
   xTaskCreate(other_task,
               "other_task",
               4 * 1024,
               NULL,
               tskIDLE_PRIORITY + 1, // default normal priority
               NULL);

   ESP_LOGI(TAG, "Awaiting Cloud connection...");
   EventBits_t bits = xEventGroupWaitBits(evt_group, EVT_CONNECTED, pdFALSE, pdFALSE, portMAX_DELAY);
   if (bits & EVT_CONNECTED) {
      ESP_LOGI(TAG, "[%s] Cloud connected event received! Continuing...", pcTaskGetName(NULL));
   }

   static bool bON = false;
   while (true) {
      // Publish Power state
      edgent_publish_ds_int("Power", (int64_t)bON);

      // Publish random Current Temperature
      double rnd = 10.0 + (esp_random() % 2501) / 100.0;
      edgent_publish_ds_float("Current Temperature", rnd, 2);

      // Publish uptime
      uint32_t uptime_sec = xTaskGetTickCount();
      edgent_publish_ds_int("uptime", uptime_sec);

      // Request metadata
      edgent_get_metadata("Device Name");

      // Toggle widget state
      edgent_set_property("uptime", "isDisabled", bON ? "false" : "true");

      bON = !bON;
      vTaskDelay(pdMS_TO_TICKS(15000));
   }
}
